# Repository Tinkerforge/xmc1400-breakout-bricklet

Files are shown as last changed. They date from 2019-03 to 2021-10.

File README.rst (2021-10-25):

XMC1400 Breakout Bricklet
=========================

This repository contains the firmware source code and the hardware design
files. The documentation generator configs can be found at
https://github.com/Tinkerforge/generators

Repository Content
------------------

software/:
 * examples/: Examples for all supported languages
 * build/: Compiled files
 * src/: Source code of firmware
 * Makefile: Makefile to build project

hardware/:
 * Contains KiCad project files and additionally schematics as PDF

datasheets/:
 * Contains datasheets for sensors and complex ICs that are used

Hardware
--------

The hardware is designed with the open source EDA Suite KiCad
(http://www.kicad.org). Before you are able to open the files,
you have to install the Tinkerforge kicad-libraries
(https://github.com/Tinkerforge/kicad-libraries). You can either clone
them directly in hardware/ or clone them in a separate folder and
symlink them into hardware/
(ln -s kicad_path/kicad-libraries project_path/hardware). After that you
can open the .pro file in hardware/ with KiCad and from there view and
modify the schematics and the PCB layout.

Software
--------

If you want to do your own Brick/Bricklet firmware development we highly
recommend that you use our build environment setup script and read the
tutorial (https://www.tinkerforge.com/en/doc/Tutorials/Tutorial_Build_Environment/Tutorial.html).

To compile the C code we recommend you to install the newest GNU Arm Embedded
Toolchain (https://launchpad.net/gcc-arm-embedded/+download).
You also need to install bricklib2 (https://github.com/Tinkerforge/bricklib2).

You can either clone it directly in software/src/ or clone it in a
separate folder and symlink it into software/src/
(ln -s bricklib_path/bricklib2 project_path/software/src/). Finally make sure to
have CMake installed (http://www.cmake.org/cmake/resources/software.html).

After that you can build the firmware by invoking make in software/.
The firmware (.zbin) can then be found in software/build/ and uploaded
with brickv (click button "Flashing" on start screen).

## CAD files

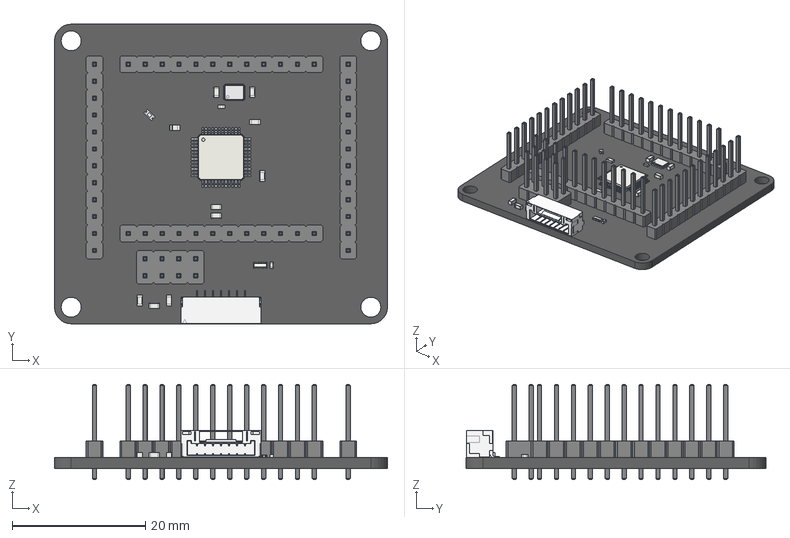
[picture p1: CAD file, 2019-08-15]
hardware/xmc1400-breakout.FCStd
50.0 x 45.0 x 14.3 mm
Pcb
U1_lqfp48_7x7_p05_5825F6DA
X1_3225_582637A1
C1_C_0603_59A57187
C2_C_0603_59A57190
C3_C_0603_59A57199
C4_C_0603_59A571A2
C5_C_0603_59A571AB
C6_C_0603_59A571B4
C8_C_0603_59A571BD
C9_C_0603_59A571C6
D3_D_0603_blue_59A571CF
FB1_C_0603_59A571DE
P1_BrickletConn_7pin_59A571E7
R1_R_0603_59A571F9
R9_R_0402_59A57202
P3_PinHeader_Straight_1x12x254mm_5898CD6C
P4_PinHeader_Straight_1x12x254mm_5898CD80
P5_PinHeader_Straight_1x12x254mm_5898CD94
P6_PinHeader_Straight_1x12x254mm_5898CDA8
P7_PinHeader_Straight_2x04x254mm_59A59EA3
C7_C_0402_5C5C7CBB
RP1_Cut_5C5C7CCB

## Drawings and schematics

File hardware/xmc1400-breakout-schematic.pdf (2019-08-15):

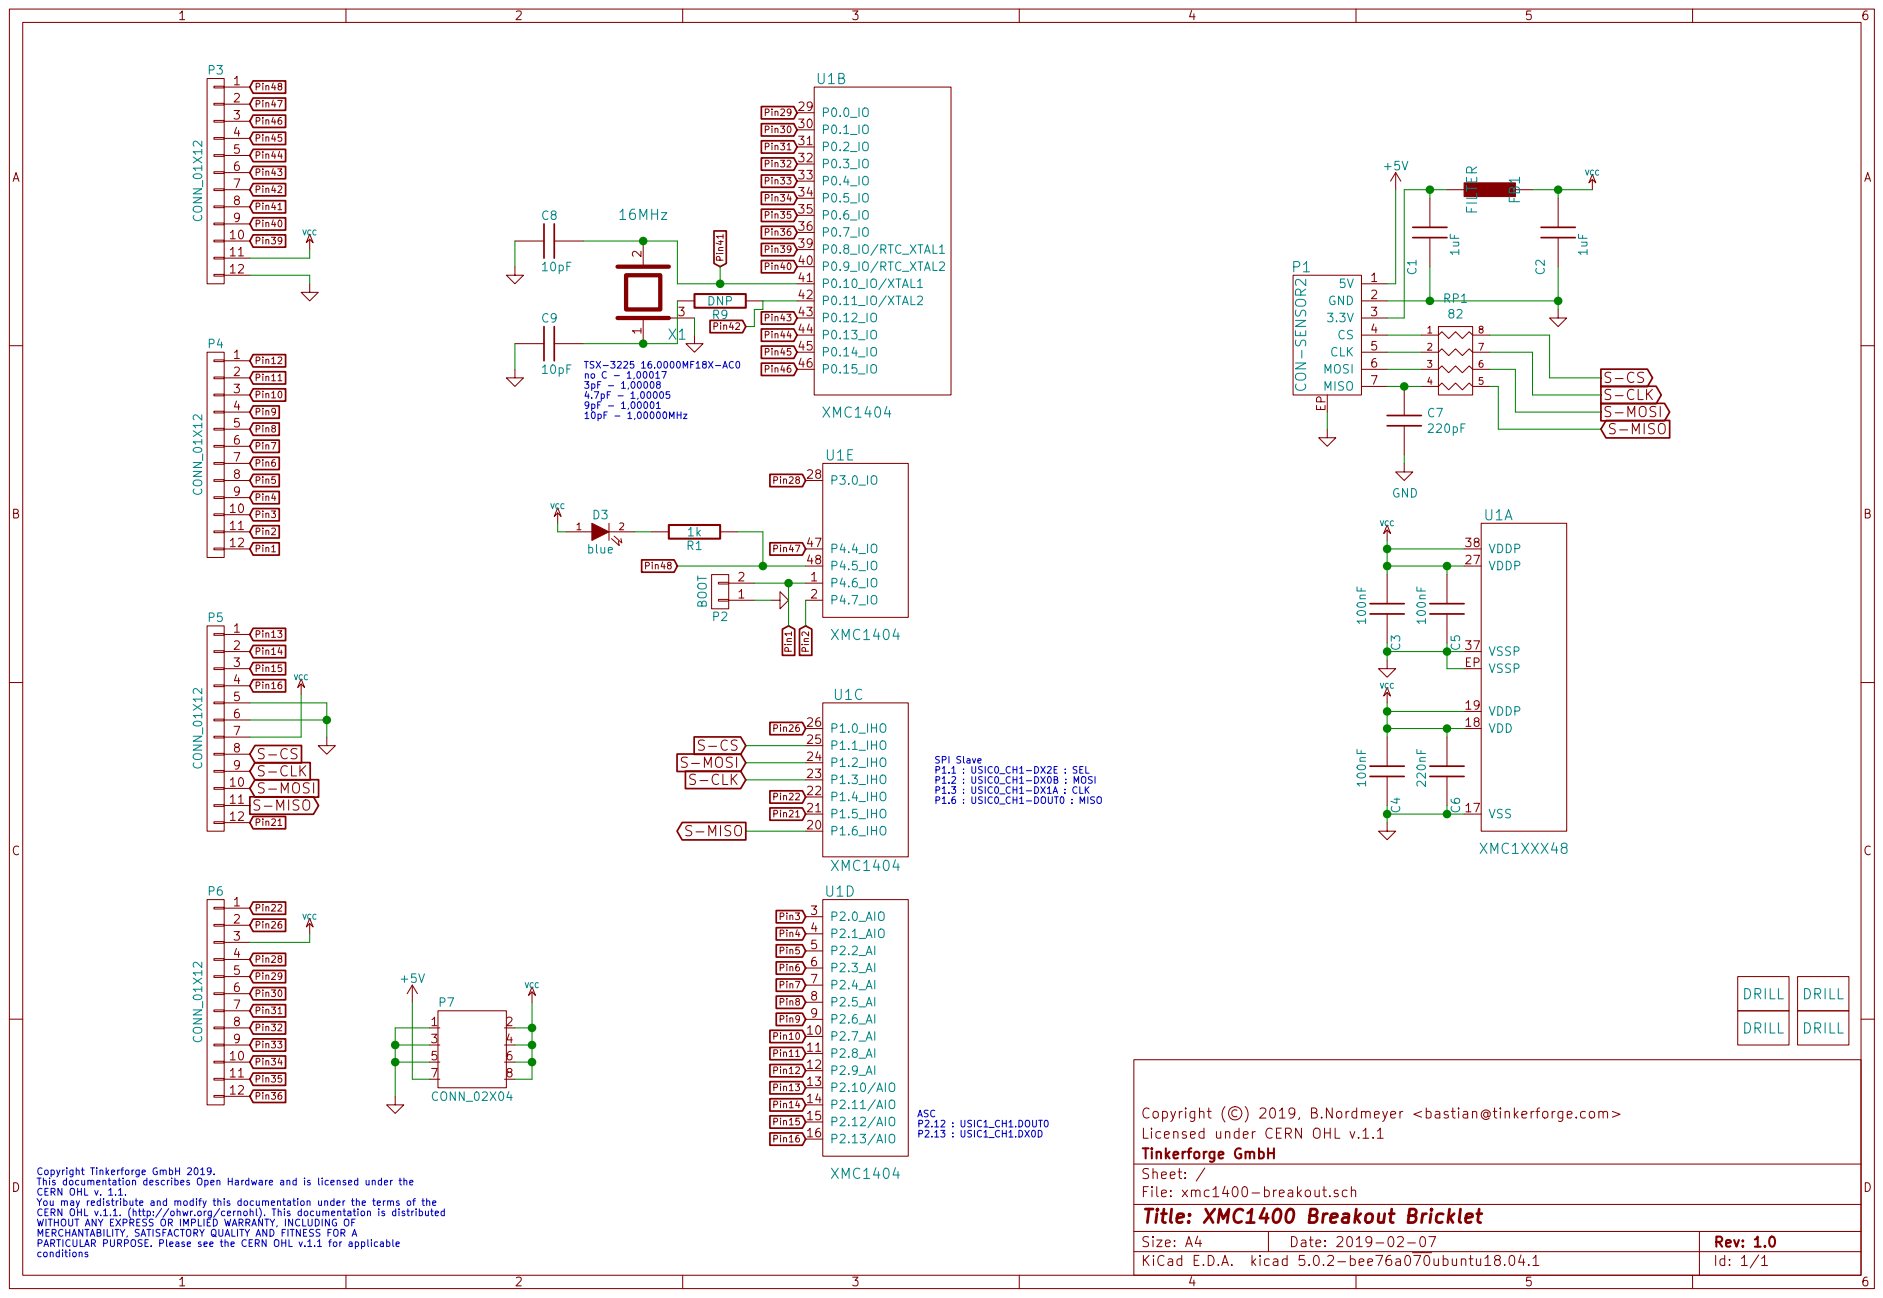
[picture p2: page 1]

7 3 | 8 P7 CONN_02X04 4

Licensed under CERN OHL v.1.1 Copyright (©) 2019, B.Nordmeyer <bastian@tinkerforge.com>

Id: 1/1 Title: XMC1400 Breakout Bricklet File: xmc1400-breakout.sch Sheet: / Tinkerforge GmbH

Copyright Tinkerforge GmbH 2019. This documentation describes Open Hardware and is licensed under the CERN OHL v. 1.1. You may redistribute and modify this documentation under the terms of the CERN OHL v.1.1. (http://ohwr.org/cernohl). This documentation is distributed WITHOUT ANY EXPRESS OR IMPLIED WARRANTY, INCLUDING OF MERCHANTABILITY, SATISFACTORY QUALITY AND FITNESS FOR A

PARTICULAR PURPOSE. Please see the CERN OHL v.1.1 for applicable

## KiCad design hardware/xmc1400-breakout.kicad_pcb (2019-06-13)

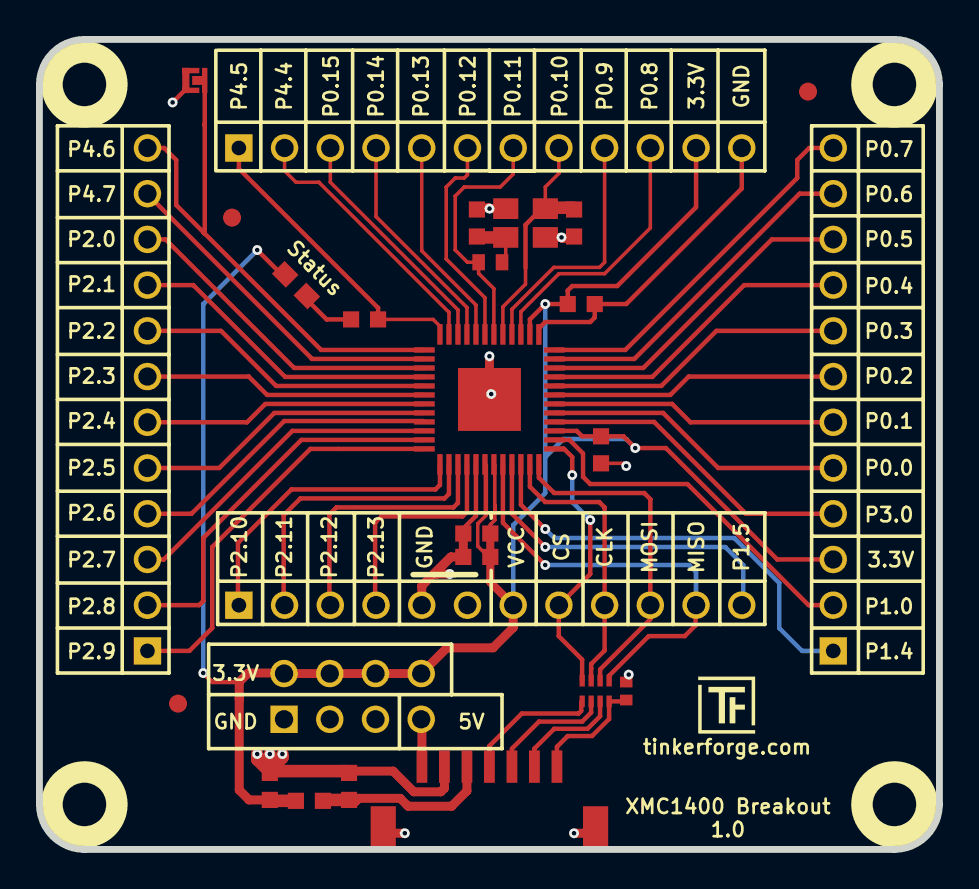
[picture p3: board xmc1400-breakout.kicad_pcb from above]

Board: 2 copper layers, 50.0 x 45.0 mm, 32 parts (0 on the bottom side), 52 nets.

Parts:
C1, C2: 1uF; C0603F
C3, C4, C5: 100nF; C0603F
C6: 220nF; C0603F
C7: 220pF; C0402F
C8, C9: 10pF; C0603F
D3: blue; D0603E
FB1: FILTER; C0603F
Fiducial_Mark: VAL**; Fiducial_Mark
Fiducial_Mark#2, Fiducial_Mark#3: VAL**; Fiducial_Mark
P1: CON-SENSOR2
P2: BOOT; SolderJumper
P3, P4, P5, P6: CONN_01X12; pin_array_12
P7: CONN_02X04; pin_array_4x2
R1: 1k; R0603F
R9: DNP; R0402E
RP1: 82; 4X0402
U1: XMC1404; QFN48-EP2
U2, U3, U4, U5: DRILL; DRILL_NP
VAL: CE_5mm
VAL#2: WEEE_7mm
X1: 16MHz; CRYSTAL_3225

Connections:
+5V: P1.1, P7.7
GND: C1.1, C2.1, C3.2, C4.2, C5.2, C6.2, C7.2, C8.2, C9.2, P1.2, P1.EP, P2.1, P3.12, P5.5, P5.6, P7.1, P7.3, P7.5, U1.17, U1.37, U1.EP, X1.3
unnamed: C1.2, FB1.2, P1.3
unnamed: C7.1, P1.7, RP1.4
unnamed: C9.1, R9.2, X1.1
unnamed: D3.2, R1.2
unnamed: P1.4, RP1.1
unnamed: P1.5, RP1.2
unnamed: P1.6, RP1.3
Pin1: P2.2, P4.12, U1.1
Pin2: P4.11, U1.2
Pin3: P4.10, U1.3
Pin4: P4.9, U1.4
Pin5: P4.8, U1.5
Pin6: P4.7, U1.6
Pin7: P4.6, U1.7
Pin8: P4.5, U1.8
Pin9: P4.4, U1.9
Pin10: P4.3, U1.10
Pin11: P4.2, U1.11
Pin12: P4.1, U1.12
Pin13: P5.1, U1.13
Pin14: P5.2, U1.14
Pin15: P5.3, U1.15
Pin16: P5.4, U1.16
Pin21: P5.12, U1.21
Pin22: P6.1, U1.22
Pin26: P6.2, U1.26
Pin28: P6.4, U1.28
Pin29: P6.5, U1.29
Pin30: P6.6, U1.30
Pin31: P6.7, U1.31
Pin32: P6.8, U1.32
Pin33: P6.9, U1.33
Pin34: P6.10, U1.34
Pin35: P6.11, U1.35
Pin36: P6.12, U1.36
Pin39: P3.10, U1.39
Pin40: P3.9, U1.40
Pin41: C8.1, P3.8, U1.41, X1.2
Pin42: P3.7, R9.1, U1.42
Pin43: P3.6, U1.43
Pin44: P3.5, U1.44
Pin45: P3.4, U1.45
Pin46: P3.3, U1.46
Pin47: P3.2, U1.47
Pin48: P3.1, R1.1, U1.48
S-CLK: P5.9, RP1.7, U1.23
S-CS: P5.8, RP1.8, U1.25
S-MISO: P5.11, RP1.5, U1.20
S-MOSI: P5.10, RP1.6, U1.24
VCC: C2.2, C3.1, C4.1, C5.1, C6.1, D3.1, FB1.1, P3.11, P5.7, P6.3, P7.2, P7.4, P7.6, P7.8, U1.18, U1.19, U1.27, U1.38

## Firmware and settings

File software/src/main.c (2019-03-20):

/* xmc1400-breakout-bricklet
 * Copyright (C) 2017-2019 Olaf Lüke <olaf@tinkerforge.com>
 *
 * main.c: Initialization for XMC1400 Breakout Bricklet
 *
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
 * You should have received a copy of the GNU Lesser General Public
 * License along with this library; if not, write to the
 * Free Software Foundation, Inc., 59 Temple Place - Suite 330,
 * Boston, MA 02111-1307, USA.
 */

#include <stdio.h>
#include <stdbool.h>

#include "configs/config.h"

#include "bricklib2/bootloader/bootloader.h"
#include "bricklib2/hal/system_timer/system_timer.h"
#include "bricklib2/logging/logging.h"
#include "communication.h"

#include "adc.h"
#include "example.h"

// The main function of a Bricklet is usually just a bunch of *_init() calls
// and while-true loop with ticks.

// Usually there is one init and tick function per driver. Example: For a
// temperature sensor IC XXX there would usually be a xxx.c and xxx.h that
// implement a xxx_init and xxx_tick function. Additionally there will be
// a XXX struct that contains all the relevant values that may be used
// in the communication.c

// A tick can not do any busy-waiting or similar, it is supposed to return as fast
// as possible. 
// We do have cooperative, non-preemtive tasks. In these you can use a never-returning
// while-true loop. The example_tick uses such a coop-task.
int main(void) {
	logging_init();
	logd("Start XMC1400 Breakout Bricklet\n\r");

	communication_init();
	adc_init();
	example_init();

	while(true) {
		bootloader_tick();
		communication_tick();
		adc_tick();
		example_tick();
	}
}

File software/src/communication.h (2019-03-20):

/* xmc1400-breakout-bricklet
 * Copyright (C) 2019 Olaf Lüke <olaf@tinkerforge.com>
 *
 * communication.h: TFP protocol message handling
 *
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
 * You should have received a copy of the GNU Lesser General Public
 * License along with this library; if not, write to the
 * Free Software Foundation, Inc., 59 Temple Place - Suite 330,
 * Boston, MA 02111-1307, USA.
 */

#ifndef COMMUNICATION_H
#define COMMUNICATION_H

#include <stdint.h>
#include <stdbool.h>

#include "bricklib2/protocols/tfp/tfp.h"
#include "bricklib2/bootloader/bootloader.h"

// Default functions
BootloaderHandleMessageResponse handle_message(const void *data, void *response);
void communication_tick(void);
void communication_init(void);

// Constants
#define XMC1400_BREAKOUT_GPIO_MODE_INPUT_TRISTATE 0
#define XMC1400_BREAKOUT_GPIO_MODE_INPUT_PULL_DOWN 1
#define XMC1400_BREAKOUT_GPIO_MODE_INPUT_PULL_UP 2
#define XMC1400_BREAKOUT_GPIO_MODE_INPUT_SAMPLING 3
#define XMC1400_BREAKOUT_GPIO_MODE_INPUT_INVERTED_TRISTATE 4
#define XMC1400_BREAKOUT_GPIO_MODE_INPUT_INVERTED_PULL_DOWN 5
#define XMC1400_BREAKOUT_GPIO_MODE_INPUT_INVERTED_PULL_UP 6
#define XMC1400_BREAKOUT_GPIO_MODE_INPUT_INVERTED_SAMPLING 7
#define XMC1400_BREAKOUT_GPIO_MODE_OUTPUT_PUSH_PULL 8
#define XMC1400_BREAKOUT_GPIO_MODE_OUTPUT_OPEN_DRAIN 9

#define XMC1400_BREAKOUT_GPIO_INPUT_HYSTERESIS_STANDARD 0
#define XMC1400_BREAKOUT_GPIO_INPUT_HYSTERESIS_LARGE 4

#define XMC1400_BREAKOUT_THRESHOLD_OPTION_OFF 'x'
#define XMC1400_BREAKOUT_THRESHOLD_OPTION_OUTSIDE 'o'
#define XMC1400_BREAKOUT_THRESHOLD_OPTION_INSIDE 'i'
#define XMC1400_BREAKOUT_THRESHOLD_OPTION_SMALLER '<'
#define XMC1400_BREAKOUT_THRESHOLD_OPTION_GREATER '>'

#define XMC1400_BREAKOUT_BOOTLOADER_MODE_BOOTLOADER 0
#define XMC1400_BREAKOUT_BOOTLOADER_MODE_FIRMWARE 1
#define XMC1400_BREAKOUT_BOOTLOADER_MODE_BOOTLOADER_WAIT_FOR_REBOOT 2
#define XMC1400_BREAKOUT_BOOTLOADER_MODE_FIRMWARE_WAIT_FOR_REBOOT 3
#define XMC1400_BREAKOUT_BOOTLOADER_MODE_FIRMWARE_WAIT_FOR_ERASE_AND_REBOOT 4

#define XMC1400_BREAKOUT_BOOTLOADER_STATUS_OK 0
#define XMC1400_BREAKOUT_BOOTLOADER_STATUS_INVALID_MODE 1
#define XMC1400_BREAKOUT_BOOTLOADER_STATUS_NO_CHANGE 2
#define XMC1400_BREAKOUT_BOOTLOADER_STATUS_ENTRY_FUNCTION_NOT_PRESENT 3
#define XMC1400_BREAKOUT_BOOTLOADER_STATUS_DEVICE_IDENTIFIER_INCORRECT 4
#define XMC1400_BREAKOUT_BOOTLOADER_STATUS_CRC_MISMATCH 5

#define XMC1400_BREAKOUT_STATUS_LED_CONFIG_OFF 0
#define XMC1400_BREAKOUT_STATUS_LED_CONFIG_ON 1
#define XMC1400_BREAKOUT_STATUS_LED_CONFIG_SHOW_HEARTBEAT 2
#define XMC1400_BREAKOUT_STATUS_LED_CONFIG_SHOW_STATUS 3

// Function and callback IDs and structs
#define FID_SET_GPIO_CONFIG 1
#define FID_GET_GPIO_INPUT 2
#define FID_SET_ADC_CHANNEL_CONFIG 3
#define FID_GET_ADC_CHANNEL_CONFIG 4
#define FID_GET_ADC_CHANNEL_VALUE 5
#define FID_GET_ADC_VALUES 6
#define FID_SET_ADC_VALUES_CALLBACK_CONFIGURATION 7
#define FID_GET_ADC_VALUES_CALLBACK_CONFIGURATION 8
#define FID_GET_COUNT 10
#define FID_SET_COUNT_CALLBACK_CONFIGURATION 11
#define FID_GET_COUNT_CALLBACK_CONFIGURATION 12

#define FID_CALLBACK_ADC_VALUES 9
#define FID_CALLBACK_COUNT 13

typedef struct {
	TFPMessageHeader header;
	uint8_t port;
	uint8_t pin;
	uint8_t mode;
	uint8_t input_hysteresis;
	bool output_level;
} __attribute__((__packed__)) SetGPIOConfig;

typedef struct {
	TFPMessageHeader header;
	uint8_t port;
	uint8_t pin;
} __attribute__((__packed__)) GetGPIOInput;

typedef struct {
	TFPMessageHeader header;
	bool value;
} __attribute__((__packed__)) GetGPIOInput_Response;

typedef struct {
	TFPMessageHeader header;
	uint8_t channel;
	bool enable;
} __attribute__((__packed__)) SetADCChannelConfig;

typedef struct {
	TFPMessageHeader header;
	uint8_t channel;
} __attribute__((__packed__)) GetADCChannelConfig;

typedef struct {
	TFPMessageHeader header;
	bool enable;
} __attribute__((__packed__)) GetADCChannelConfig_Response;

typedef struct {
	TFPMessageHeader header;
	uint8_t channel;
} __attribute__((__packed__)) GetADCChannelValue;

typedef struct {
	TFPMessageHeader header;
	uint16_t value;
} __attribute__((__packed__)) GetADCChannelValue_Response;

typedef struct {
	TFPMessageHeader header;
} __attribute__((__packed__)) GetADCValues;

typedef struct {
	TFPMessageHeader header;
	uint16_t values[8];
} __attribute__((__packed__)) GetADCValues_Response;

typedef struct {
	TFPMessageHeader header;
	uint32_t period;
	bool value_has_to_change;
} __attribute__((__packed__)) SetADCValuesCallbackConfiguration;

typedef struct {
	TFPMessageHeader header;
} __attribute__((__packed__)) GetADCValuesCallbackConfiguration;

typedef struct {
	TFPMessageHeader header;
	uint32_t period;
	bool value_has_to_change;
} __attribute__((__packed__)) GetADCValuesCallbackConfiguration_Response;

typedef struct {
	TFPMessageHeader header;
	uint16_t values[8];
} __attribute__((__packed__)) ADCValues_Callback;


// Function prototypes
BootloaderHandleMessageResponse set_gpio_config(const SetGPIOConfig *data);
BootloaderHandleMessageResponse get_gpio_input(const GetGPIOInput *data, GetGPIOInput_Response *response);
BootloaderHandleMessageResponse set_adc_channel_config(const SetADCChannelConfig *data);
BootloaderHandleMessageResponse get_adc_channel_config(const GetADCChannelConfig *data, GetADCChannelConfig_Response *response);
BootloaderHandleMessageResponse get_adc_channel_value(const GetADCChannelValue *data, GetADCChannelValue_Response *response);
BootloaderHandleMessageResponse get_adc_values(const GetADCValues *data, GetADCValues_Response *response);
BootloaderHandleMessageResponse set_adc_values_callback_configuration(const SetADCValuesCallbackConfiguration *data);
BootloaderHandleMessageResponse get_adc_values_callback_configuration(const GetADCValuesCallbackConfiguration *data, GetADCValuesCallbackConfiguration_Response *response);

// Callbacks
bool handle_adc_values_callback(void);
bool handle_count_callback(void);

#define COMMUNICATION_CALLBACK_TICK_WAIT_MS 1
#define COMMUNICATION_CALLBACK_HANDLER_NUM 2
#define COMMUNICATION_CALLBACK_LIST_INIT \
	handle_adc_values_callback, \
	handle_count_callback, \


#endif

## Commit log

2017-02-07 Adding current unfinished version
    [xmc1400_breakout.kicad_pcb, xmc1400_breakout.sch]
2017-02-07 Add VCC connections
    [xmc1400_breakout.kicad_pcb]
2017-02-07 removing rescue lib
    [xmc1400_breakout.sch]
2017-02-07 Optical improvements
    [xmc1400_breakout.sch]
2017-02-07 Add pin markings
    [xmc1400_breakout.kicad_pcb]
2017-02-07 Fix fiducial mark position top left
    [xmc1400_breakout.kicad_pcb]
2017-03-27 Add stub software for XMC1400 breakout
    [cmake_config_custom.txt]
2017-08-29 Add 3d information
    [xmc1400_breakout.kicad_pcb, xmc1400_breakout.sch]
2017-08-29 Add more headers (GND, VCC, 5V)
    [xmc1400_breakout.kicad_pcb, xmc1400_breakout.sch]
2017-09-14 Fix typo
    [xmc1400_breakout.kicad_pcb]
2017-09-14 Fix conductor path connection
    [xmc1400_breakout.kicad_pcb]
2017-10-13 Add missing bootstrapper configuration
    [config_custom_bootstrapper.h]
2019-02-07 name change and added sym lib table
    [xmc1400-breakout-bricklet.kicad_pcb, xmc1400-breakout-bricklet.sch]
2019-02-07 added text on back silkscreen
    [xmc1400-breakout-bricklet.kicad_pcb, xmc1400-breakout-bricklet.sch]
2019-02-07 added filter resitor and cap in dataline
    [xmc1400-breakout-bricklet.kicad_pcb]
2019-03-19 Use relative path to kicad-libraries
2019-03-20 Add example firmware for XMC1400 Breakout Bricklet
    [cmake_config_custom.txt]
2019-04-03 Enable post calibration
2019-05-15 fix file names
    [xmc1400-breakout.kicad_pcb, xmc1400-breakout.sch]
2019-06-12 specify processor
    [xmc1400-breakout.kicad_pcb, xmc1400-breakout.sch]
2019-06-13 specify resistor
    [xmc1400-breakout.kicad_pcb, xmc1400-breakout.sch]
2019-06-13 fix connector properties
    [xmc1400-breakout.kicad_pcb]
2019-08-15 add 3d data
    [xmc1400-breakout.FCStd]
2019-08-15 Turn external oscillator off (by default)
    Can be enabled by the user if needed
    [config_custom_bootloader.h]
2019-08-15 Fix input hysteresis check
    [communication.c]
2019-08-15 fix schematic symbols, add pdf
    [xmc1400-breakout.sch]
2020-04-07 examples: rust: Always block when calling bindings functions.
    [example_gpio.rs]
2020-09-02 uc: Add example driver note.
2021-10-25 Update KiCad link
    https://www.kicad.org/blog/2021/10/Avoid-links-to-former-kicad-domain/
2022-04-27 uc: Adapt to bindings changes
    [example_gpio.c]

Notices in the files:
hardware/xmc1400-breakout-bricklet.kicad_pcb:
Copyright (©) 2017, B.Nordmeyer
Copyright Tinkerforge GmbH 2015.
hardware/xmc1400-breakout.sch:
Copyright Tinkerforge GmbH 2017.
